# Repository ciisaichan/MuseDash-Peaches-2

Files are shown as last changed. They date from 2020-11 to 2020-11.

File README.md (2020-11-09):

# MuseDash-Peaches-2
开源的触摸式音游控制器，可以兼容使用DFJK按键的下落式音游。

### 视频
<https://www.bilibili.com/video/BV165411L7LT>

### 目录/文件
- [images](https://github.com/ciisaichan/MuseDash-Peaches-2/tree/main/images "images") - 介绍用图片资源
- [mush_dash_peaches2](https://github.com/ciisaichan/MuseDash-Peaches-2/tree/main/mush_dash_peaches2 "mush_dash_peaches2") - Arduino单片机源代码
- [pcb_gerber](https://github.com/ciisaichan/MuseDash-Peaches-2/tree/main/pcb_gerber "pcb_gerber") - PCB生产文件
- [shell](https://github.com/ciisaichan/MuseDash-Peaches-2/tree/main/shell "shell") - 用于外壳切割的矢量图片
- [BOM.xlsx](https://github.com/ciisaichan/MuseDash-Peaches-2/blob/main/BOM.xlsx "BOM.xlsx") - 配件配单表以及原件对应的焊盘位置
- [schematic.pdf](https://github.com/ciisaichan/MuseDash-Peaches-2/blob/main/schematic.pdf "schematic.pdf") - 电路原理图

### PCB预览图/原理图
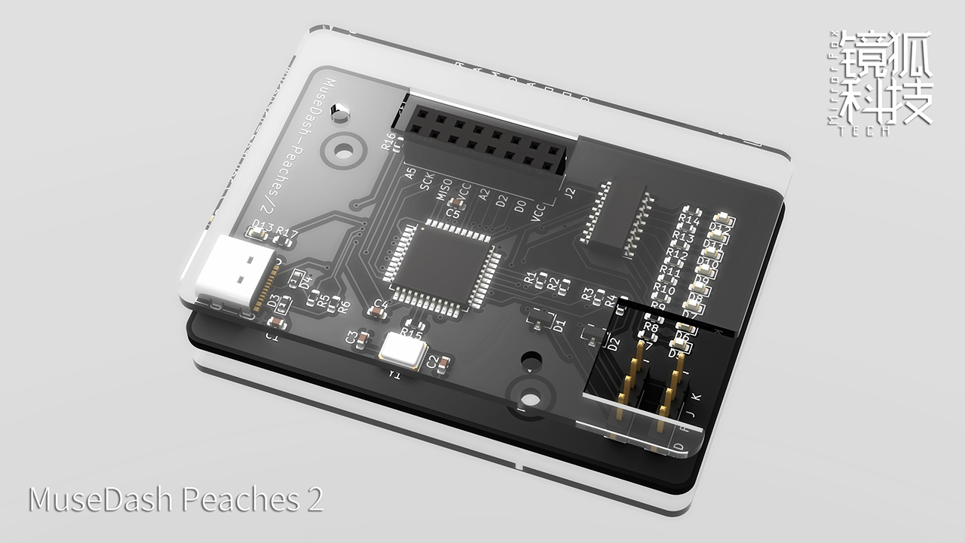
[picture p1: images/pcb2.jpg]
PCB预览图

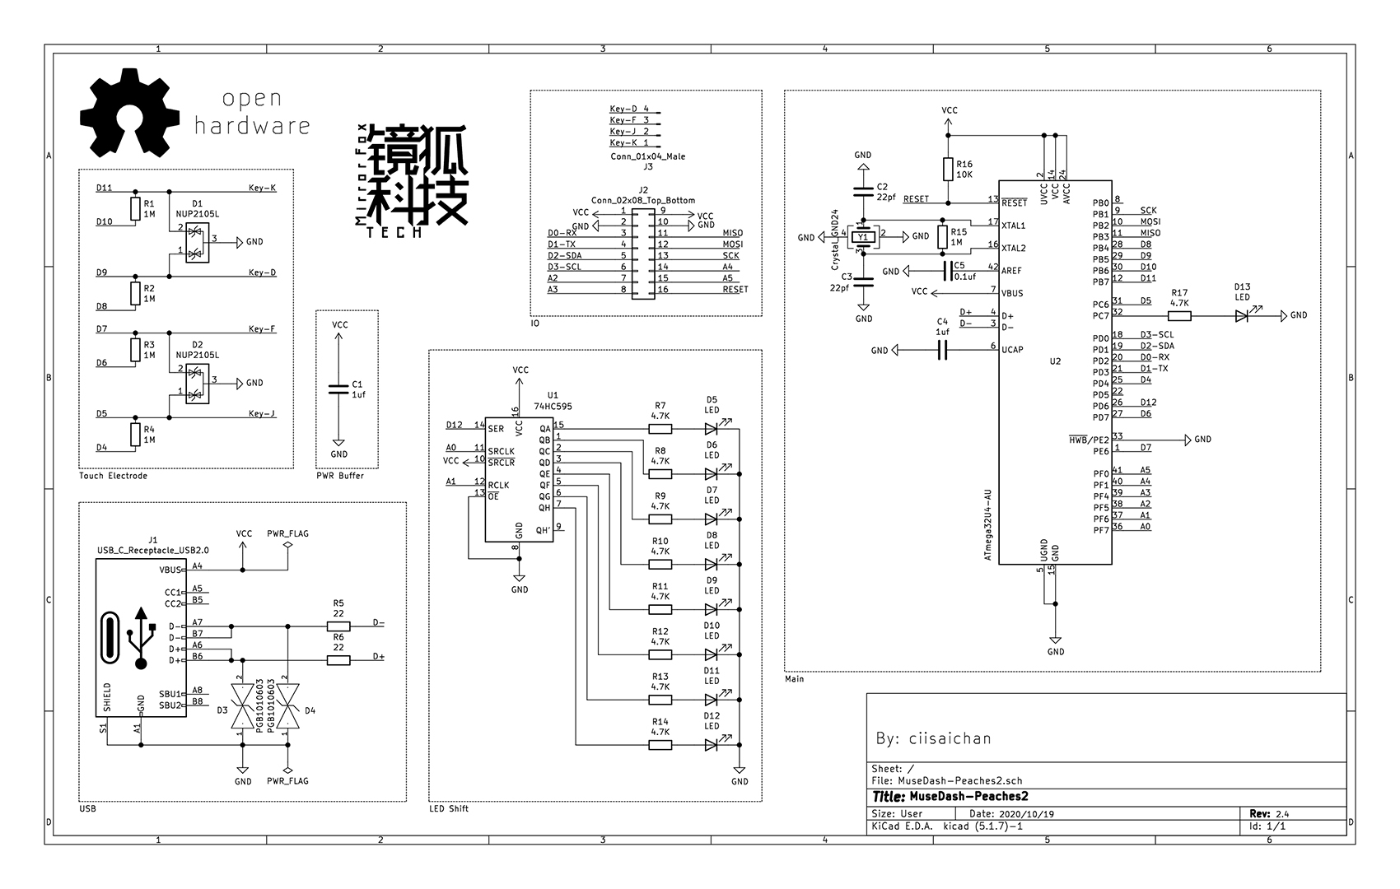
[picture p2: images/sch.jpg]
电路原理图


### 功能
此版本配备4个分别对应DFJK按键的触摸电极，就是开发板接线柱的4个接口，
同时还有74HC595驱动的8个LED灯，可以自己进行编程，
也可以使用剩余的IO口加入自己的功能，

### 使用方法
将开发板接线柱上方橘色的把手往前推，接入导线再松开，之后可以将导线接到任意导体（如水果，锡箔纸）用来充当按键，将开发板与电脑连接后会被识别为HID键盘，此时触摸连接的导体就会发送对应的按键信号到电脑上，可以用记事本之类输入文本的地方进行测试。

### 制作指南
如果觉得此版本难度较大可以选择之前的版本：
<https://github.com/ciisaichan/MuseDash-Peaches>

1. 此版本因为涉及贴片焊接，所以需要工具以及焊接技能，可以使用PCB厂家提供的SMT贴片服务，这样到手就是成品，比较特殊的零件就是 "4p免螺丝接线端子" 需要自己单独购买和焊接。
2. 硬件部分制作完成后需要对单片机烧写bootloader才可以用Arduino IDE编程。[bootloader烧写教程](https://blog.csdn.net/sysjtlwx/article/details/73824903 "bootloader烧写教程")
3. bootloader烧写完成后将开发板通过USB连接电脑，打开Arduino IDE并打开源代码，选择开发板为 "Arduino Leonardo"并选择开发板对应端口，点击 "上传" 即可。（如果编译错误请安装 "CapacitiveSensor" 库）
4. 开发板固定孔以及外壳固定孔的直径为2.5mm，如需要请选择2.5mm直径的螺丝

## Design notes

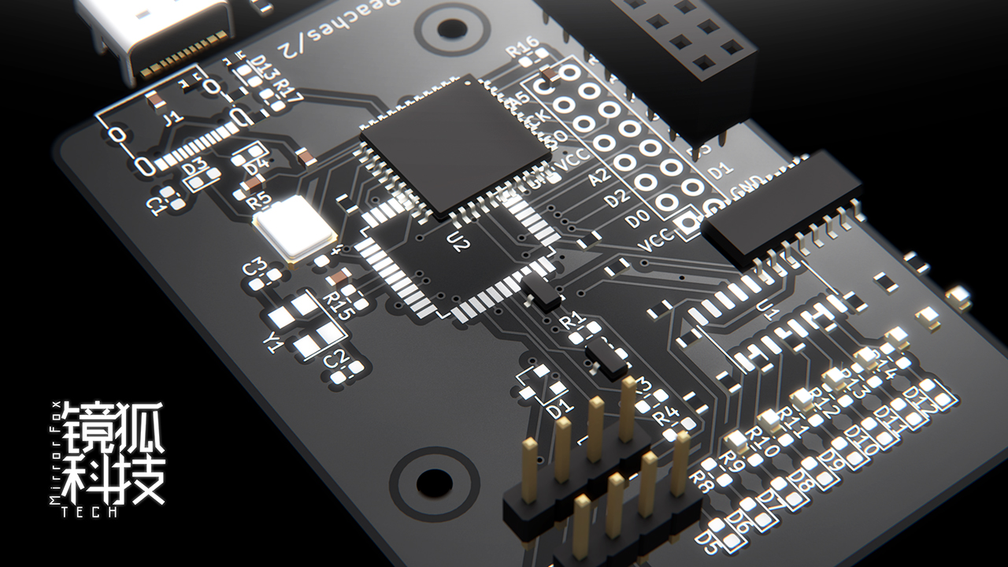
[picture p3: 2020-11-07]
images/pcb.jpg

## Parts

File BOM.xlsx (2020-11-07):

物料BOM清单
序号 | 名称 | 型号/规格 | 封装 | 用量 | 品牌 | 商品编号 | 焊盘编号
1 | 4.7KΩ ±1% | RMC06034.7K1%N | 0603 | 9 | Tyohm(幸亚电阻) | C269713 | R17,R14,R13,R12,R11,R10,R9,R8,R7,
2 | 100nF(104) -20%,+80% 25V | 0603F104Z250CT | 0603 | 1 | 华新科(Walsin) | C387985 | C5,
3 | 1uF 16V ±20% | CL10X105MO8NNNC | 0603 | 2 | SAMSUNG(三星) | C730454 | C1,C4,
4 | SMD-5032_4P 16M 20pf 20ppm | TXM16M0004503LDCDO00T | SMD-5032_4P | 1 | TAE(雅晶鑫) | C362491 | Y1,
5 | 22Ω(22R0) ±1% | RS-03K22R0FT | 0603 | 2 | FH(风华) | C174301 | R6,R5,
6 | 蓝色 LED | D-060306B1 | 0603 | 9 | 方舟 ARKLED | C118339 | D13,D12,D11,D10,D9,D8,D7,D6,D5,
7 | NUP2105L | NUP2105L | SOT-23(SOT-23-3) | 2 | DOWO(东沃) | C284104 | D2,D1,
8 | ATMEGA32U4-AU | ATMEGA32U4-AU | QFP-44_10x10x08P | 1 | MICROCHIP(美国微芯) | C44854 | U2,
9 | 10KΩ(1002) ±1% | RC0603FR-0710KL | 0603 | 1 | YAGEO(国巨) | C98220 | R16,
10 | 1MΩ ±1% | 0603WAF1004T5E | 0603 | 5 | UNI-ROYAL(厚声) | C22935 | R15,R4,R3,R2,R1,
11 | 22pF(220) ±5% 50V | CC0603JRNPO9BN220 | 0603 | 2 | YAGEO(国巨) | C105620 | C3,C2,
12 | 2.54mm 2*8P 直 排母 | 2.54mm,2×8双排排母 | Through Hole | 1 | BOOMELE(博穆精密) | C30734 | J2,
13 | usb连接器 3.1TYPE-C 母座 16P 板上,镀镍不锈钢,贴片 | U262-161N-4BVC11 | SMT | 1 | XKB Connectivity(中国星坤) | C319148 | J1,
14 | SM74HC595D | SM74HC595D | SOP-16_150mil | 1 | 明微 | C93838 | U1,
15 | PGB1010603MR | PGB1010603MR | 0603 | 2 | Littelfuse(美国力特) | C142698 | D4,D3,
16 | 4p免螺丝接线端子 | KF141R-2.54mm 弯针 |  | 1 | 晨诚电子 | https://item.taobao.com/item.htm?spm=a1z09.2.0.0.2f882e8dLpPUch&id=569344745652 | J3,J3,

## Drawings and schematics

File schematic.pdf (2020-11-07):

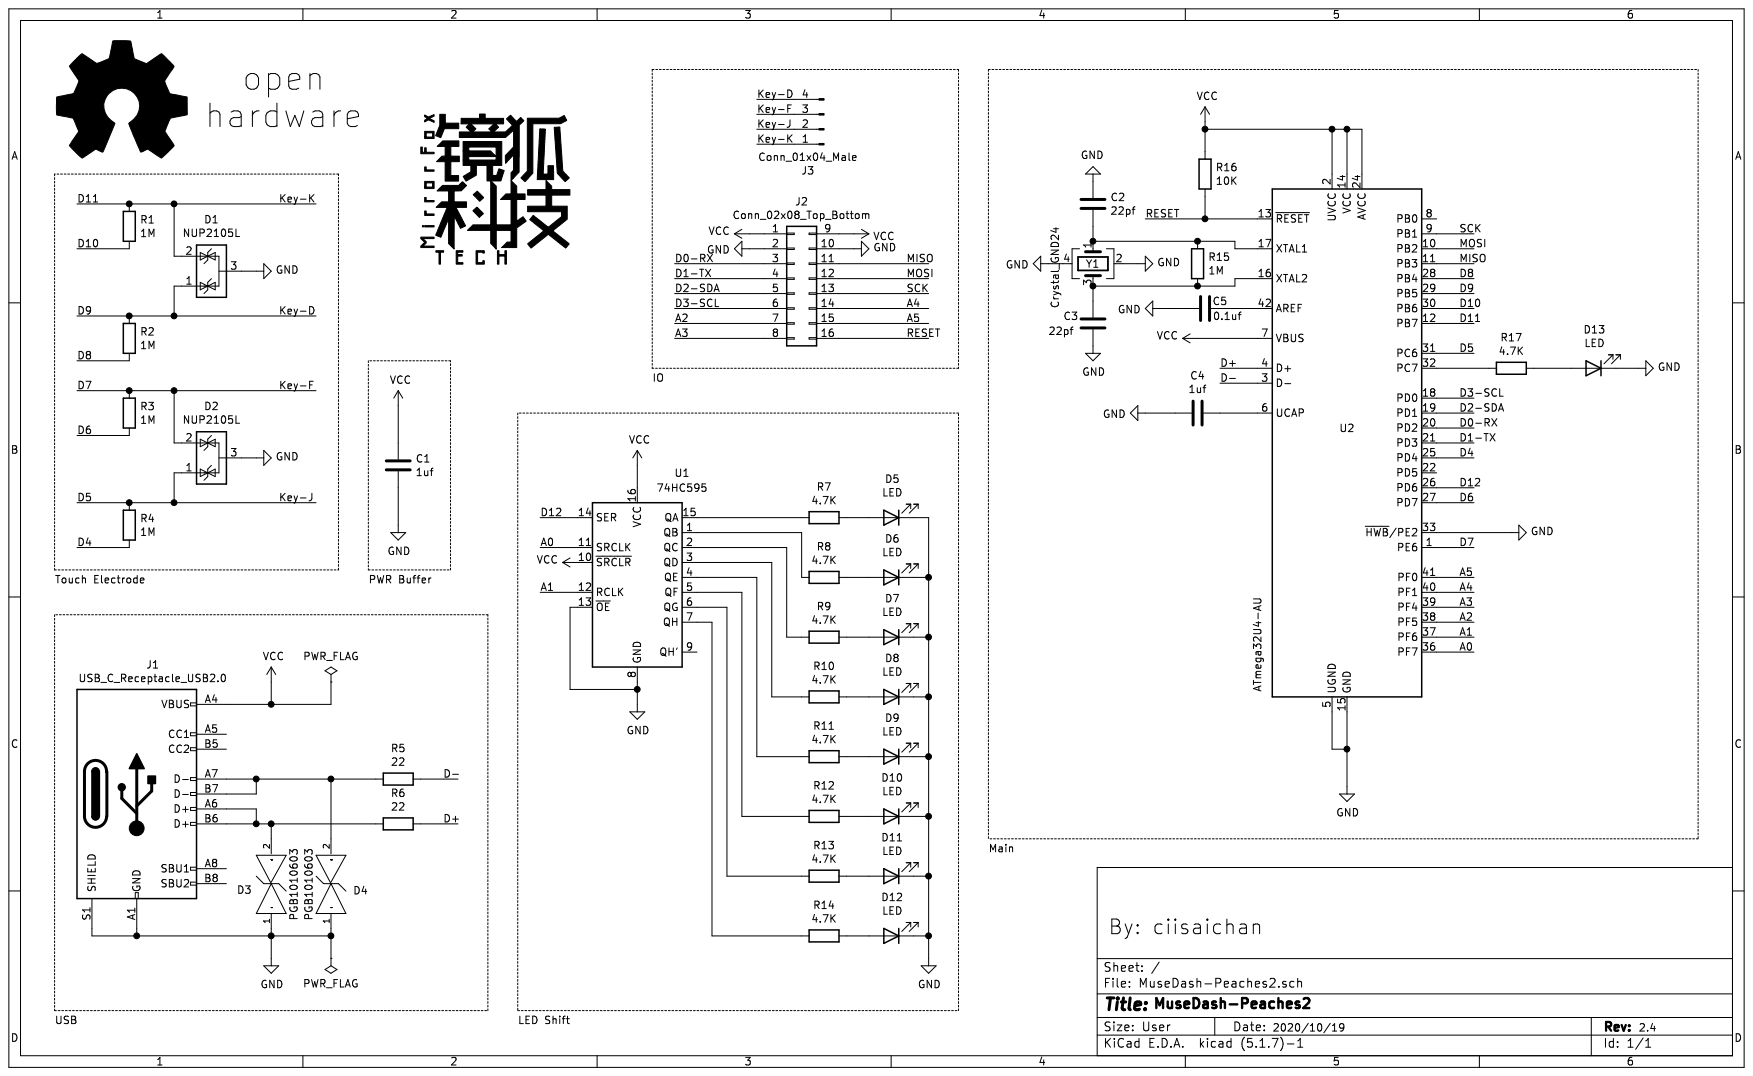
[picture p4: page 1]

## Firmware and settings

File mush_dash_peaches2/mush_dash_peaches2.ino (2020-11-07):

#include <CapacitiveSensor.h>
#include <Keyboard.h>

// LED移位寄存器引脚
int latchPin = A1; //锁存引脚
int clockPin = A0; //时钟引脚
int dataPin = 12; //数据引脚


CapacitiveSensor   cs_d = CapacitiveSensor(8, 9);
CapacitiveSensor   cs_f = CapacitiveSensor(6, 7);

CapacitiveSensor   cs_j = CapacitiveSensor(4, 5);
CapacitiveSensor   cs_k = CapacitiveSensor(10, 11);

bool f_push = false;
bool j_push = false;
bool d_push = false;
bool k_push = false;

// 按键按下电容阈值 （大于此值时）
long press_val = 800;
// 按键释放电容阈值（小于此值时）
long release_val = 600;
// 电容值判断超时时间（单位：毫秒）
long time_out = 20;
// 电容值采样率（越大电容值越准确）
byte cp_resolution = 50;

// 取消注释进入调试模式
//#define DEBUG

void setup()
{
  Serial.begin(9600);
  pinMode(latchPin, OUTPUT);
  pinMode(clockPin, OUTPUT);
  pinMode(dataPin, OUTPUT);
  cs_d.set_CS_Timeout_Millis(time_out);
  cs_f.set_CS_Timeout_Millis(time_out);
  cs_j.set_CS_Timeout_Millis(time_out);
  cs_k.set_CS_Timeout_Millis(time_out);
  setLEDs(0);
  Keyboard.begin();
}

void loop()
{
#ifdef DEBUG
  long start = millis();
#endif
  long cp1 =  cs_f.capacitiveSensor(cp_resolution);
  if (cp1 == -2) {
    cp1 = 1200;
  }
  if (cp1 > press_val && !f_push) {
    Keyboard.press('f');
    f_push = true;
  } else if (cp1 < release_val && f_push) {
    Keyboard.release('f');
    f_push = false;
  }

  long cp2 =  cs_j.capacitiveSensor(cp_resolution);
  if (cp2 == -2) {
    cp2 = 1200;
  }
  if (cp2 > press_val && !j_push) {
    Keyboard.press('j');
    j_push = true;
  } else if (cp2 < release_val && j_push) {
    Keyboard.release('j');
    j_push = false;
  }

  long cp3 =  cs_d.capacitiveSensor(cp_resolution);
  if (cp3 == -2) {
    cp3 = 1200;
  }
  if (cp3 > press_val && !d_push) {
    Keyboard.press('d');
    d_push = true;
  } else if (cp3 < release_val && d_push) {
    Keyboard.release('d');
    d_push = false;
  }

  long cp4 =  cs_k.capacitiveSensor(cp_resolution);
  if (cp4 == -2) {
    cp4 = 1200;
  }
  if (cp4 > press_val && !k_push) {
    Keyboard.press('k');
    k_push = true;
  } else if (cp4 < release_val && k_push) {
    Keyboard.release('k');
    k_push = false;
  }

  boolean LEDs[] = {0, 0, 0, 0, 0, 0, 0, 0};
  if (d_push) {
    LEDs[7] = true;
    LEDs[6] = true;
  }
  if (f_push) {
    LEDs[5] = true;
    LEDs[4] = true;
  }
  if (j_push) {
    LEDs[3] = true;
    LEDs[2] = true;
  }
  if (k_push) {
    LEDs[1] = true;
    LEDs[0] = true;
  }
  setLEDs(LEDs);

#ifdef DEBUG
  Serial.print(millis() - start);
  Serial.print("ms");
  Serial.print("\t");
  Serial.print(cp1);
  Serial.print("\t");
  Serial.print(cp2);
  Serial.print("\t");
  Serial.print(cp3);
  Serial.print("\t");
  Serial.print(cp4);
  Serial.print("\t");
  for (int x = 0; x < 8; x++) {
    Serial.print(LEDs[x]);
  }
  Serial.println();
  delay(10);
#endif

}

void setLEDs(boolean data[]) {
  digitalWrite(latchPin, LOW);

  for (int x = 0; x < 8; x++) {
    digitalWrite(clockPin, LOW);
    digitalWrite(dataPin, data[x]);
    digitalWrite(clockPin, HIGH);
  }

  digitalWrite(latchPin, HIGH);
}

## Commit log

2020-11-07 添加PCB生产文件
    [MuseDash-Peaches2-Bottom_Cu.gbr, MuseDash-Peaches2-Bottom_Mask.gbr, MuseDash-Peaches2-Bottom_Paste.gbr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]
2020-11-07 添加BOM配单表
    [BOM.xlsx]
2020-11-07 添加Arduino源代码
2020-11-07 添加电路原理图
2020-11-07 添加图片
2020-11-07 更新BOM配单表
    [BOM.xlsx]
2020-11-09 添加外壳切割文件
